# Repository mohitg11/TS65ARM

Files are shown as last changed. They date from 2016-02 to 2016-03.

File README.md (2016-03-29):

# TS65 - ARM Based
The Split 65% Keyboard - ARM Based

This is a custom 65% style keyboard that is split in the middle to provide a more ergonomic option whilest not being drastically different from the standard stagger used on keyboards

#Features
- Open Source Design
- Fully Programmable Keys
- Split design for better ergonomics, while maintaining the currently "standard" keyboard layout
- PCBs and case designed so that the two sides can be connected into standard 65% without split
- Infinite layers
- Alps & Cherry (PCB and Plate) switches supported
- PCB mount stabs supported
- All keys individually lit. LED on top to maintain compatibility with the few backlit keysets out there
- 18 RGB SMD LEDs on the bottom of the PCB for under/side glow
- 3 indicator LEDs
- Individual resistors for the LEDs not required as it uses a dedicated LED driver
- Either side (Left or right) can be connected to the PC
- USB 3.0 Type A and USB Type C are used.
- Using larger (0805) capacitors and resistors so it is easy to hand-solder
- SMD (SOD-123) diodes only

#Layout options
- Split backspace
- Split left shift
- ISO support
- Off-center capslock
- 2.75 and 1.75 right shift
- Lots of options for bottom row

In the below image you can see the different options available, the top four rows represent the four rows of th keyboard and the options for the final keyboard row is represented by the remaining rows in the image.
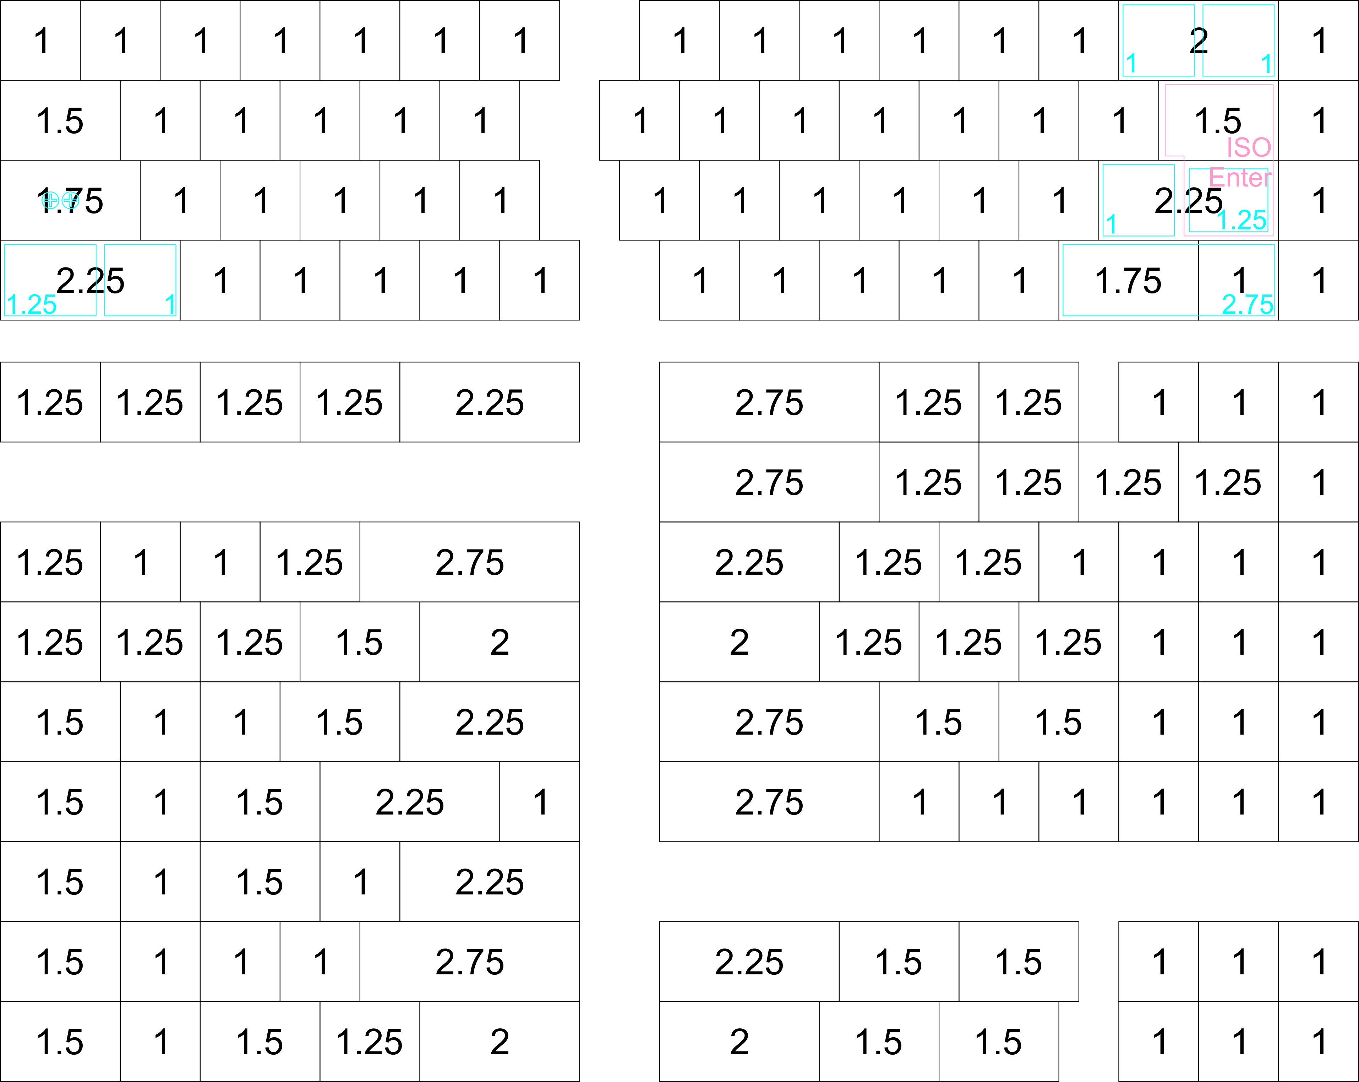
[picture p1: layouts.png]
Layout Options


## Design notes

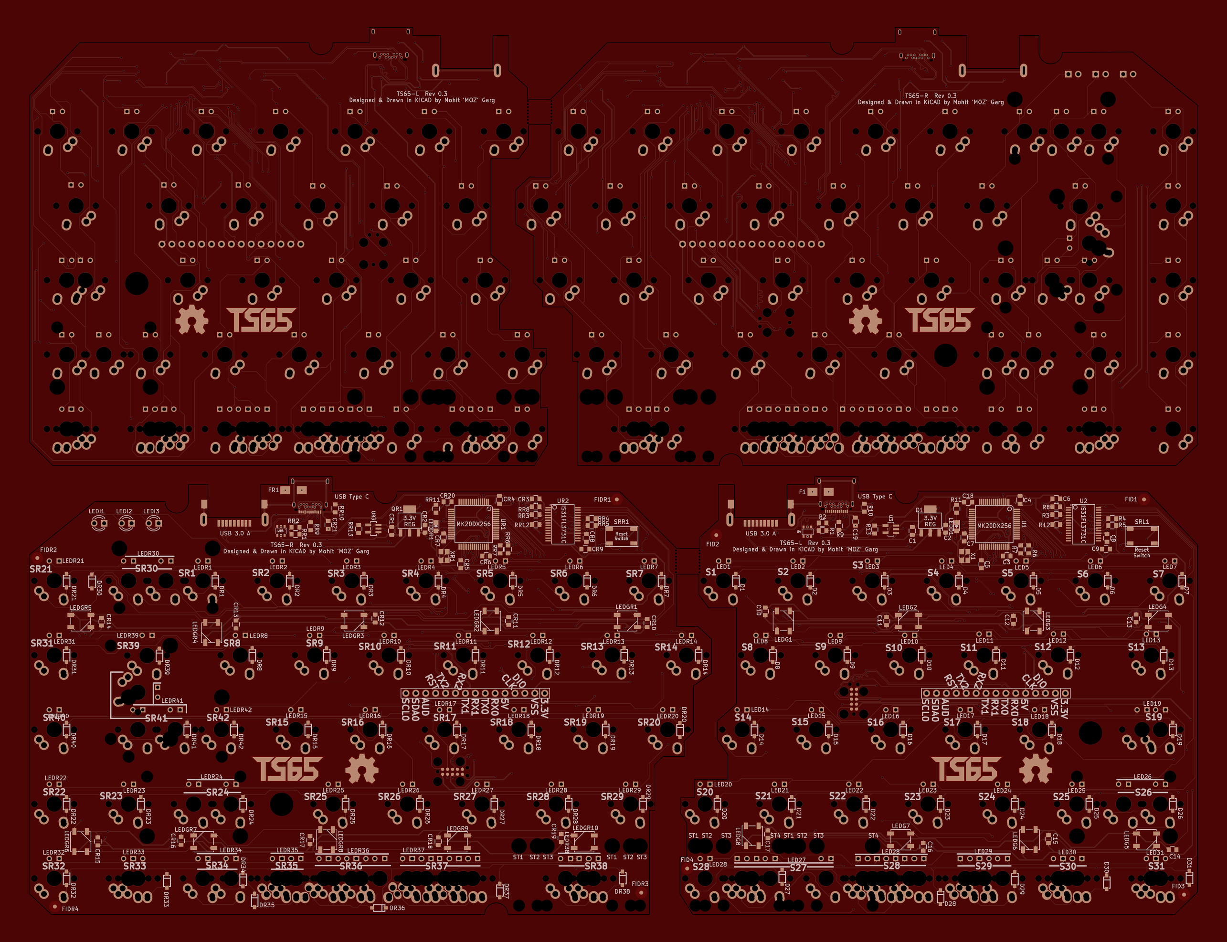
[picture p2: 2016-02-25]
PCBOutput.png

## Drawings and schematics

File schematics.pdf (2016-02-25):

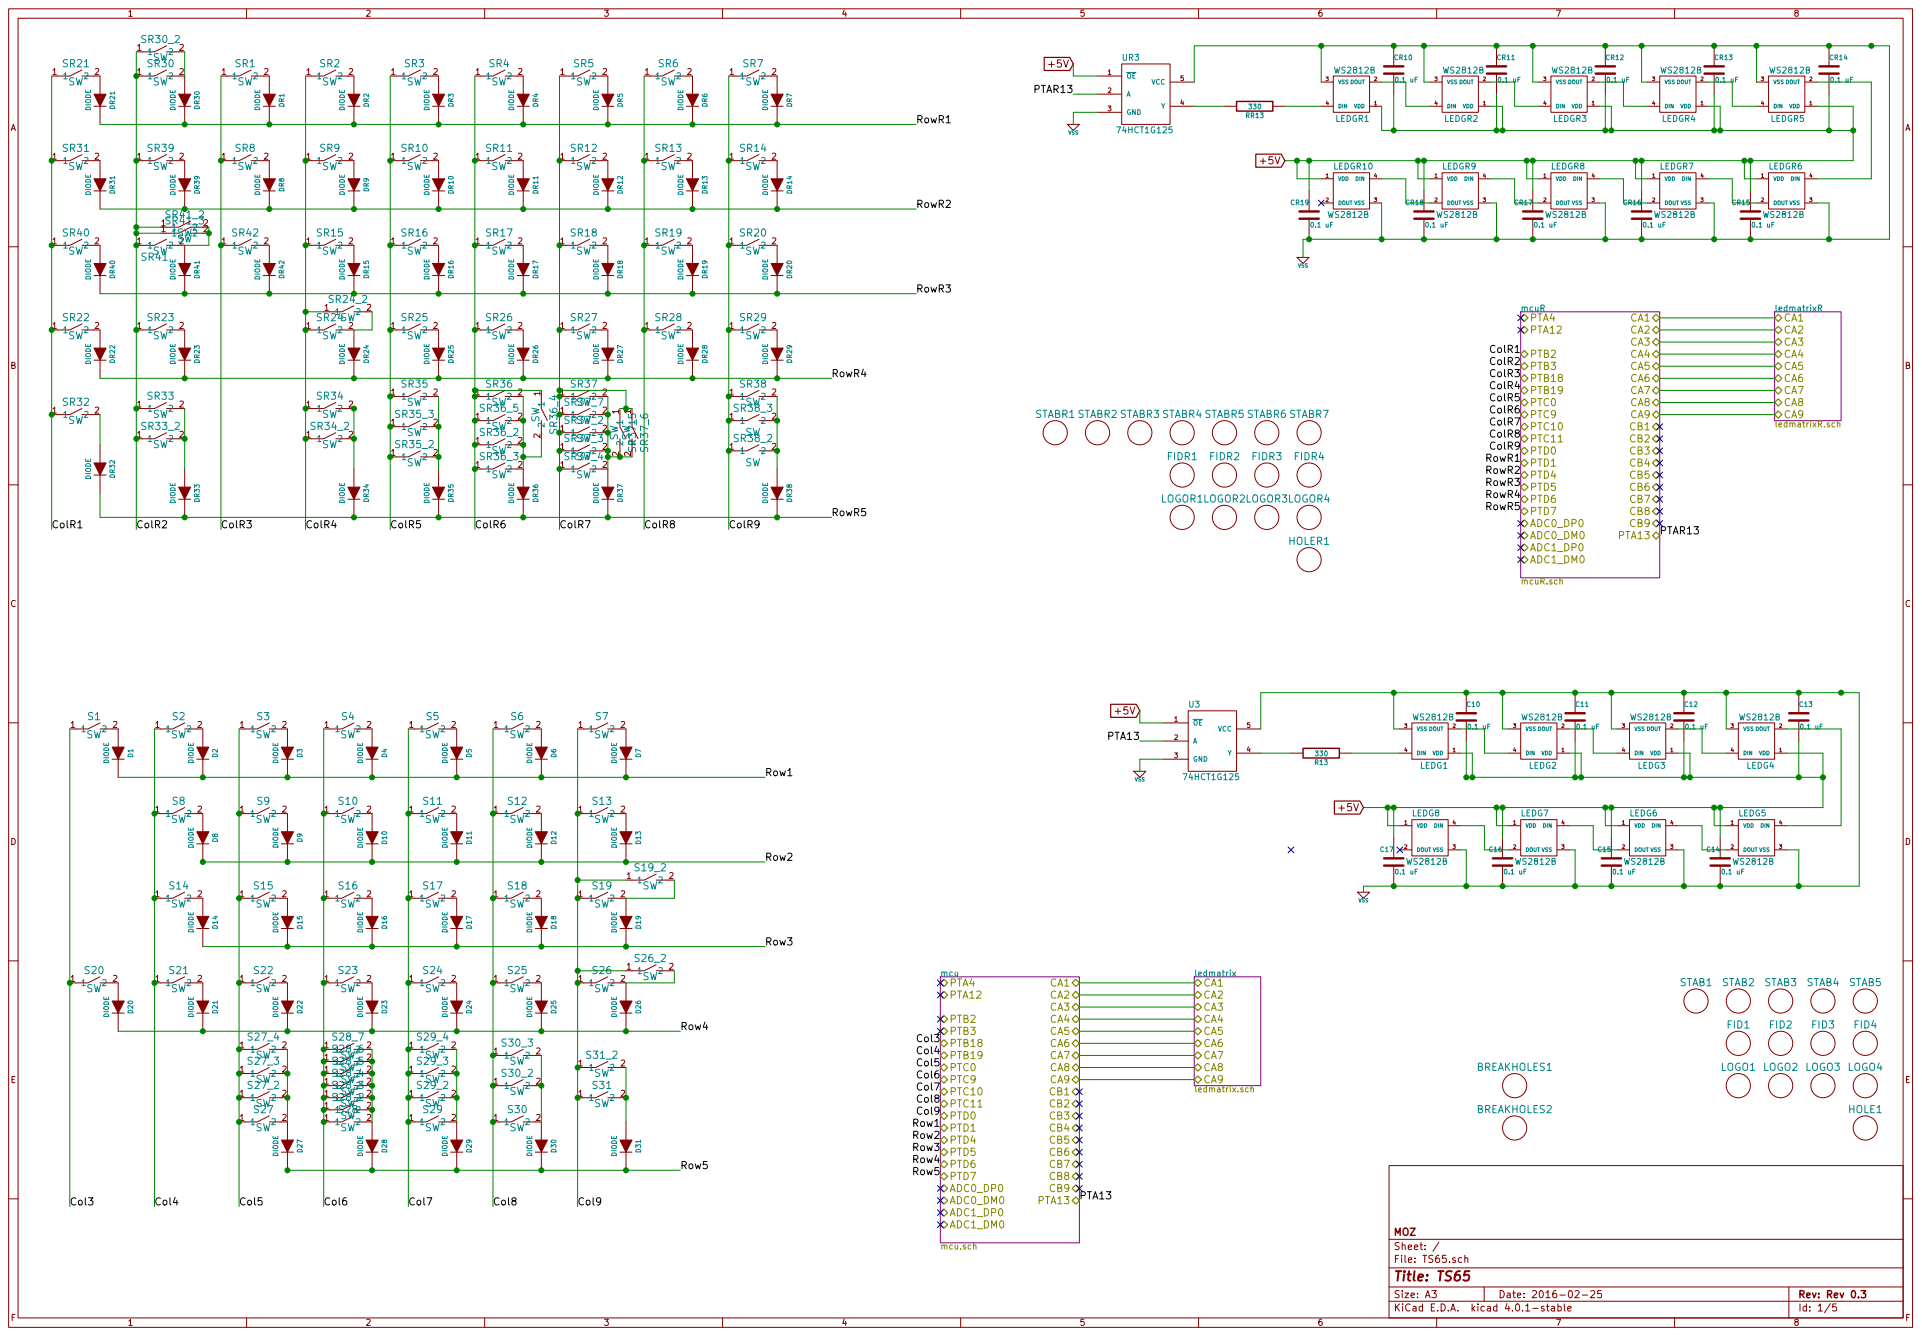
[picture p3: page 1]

File: TS65.sch Sheet: / MOZ

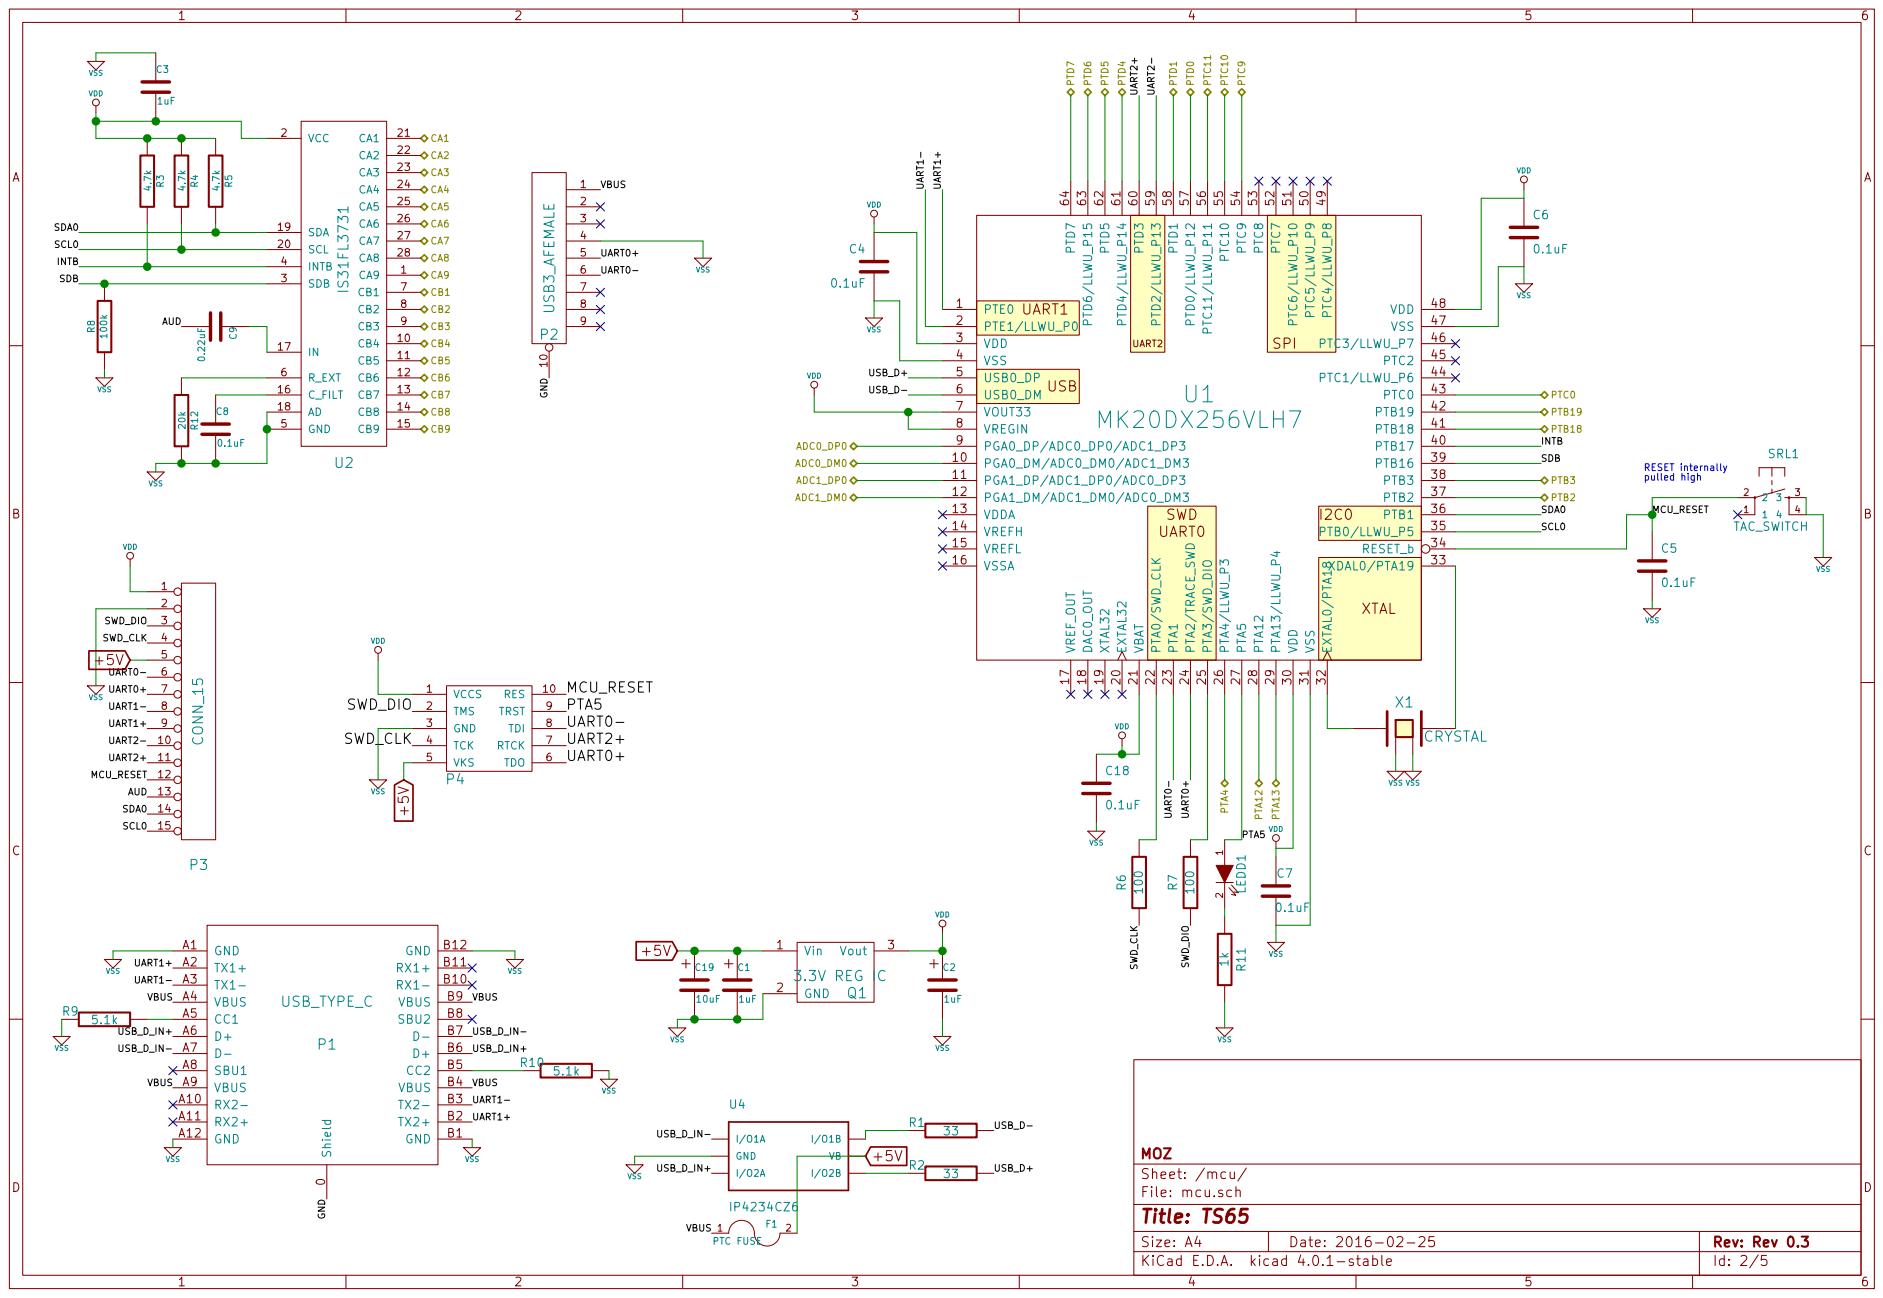
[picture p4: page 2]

0 GND A1 GND B1 TX1+ A2 TX2+ B2 TX1- A3 TX2- B3 VBUS A4 VBUS B4 CC1 A5 CC2 B5 D+ A6 D+ B6 D- A7 D- B7 SBU1 A8 SBU2 B8 VBUS A9 VBUS B9 RX2- A10 RX1- B10 RX2+ A11 RX1+ B11 GND A12 GND B12 P1 USB_TYPE_C

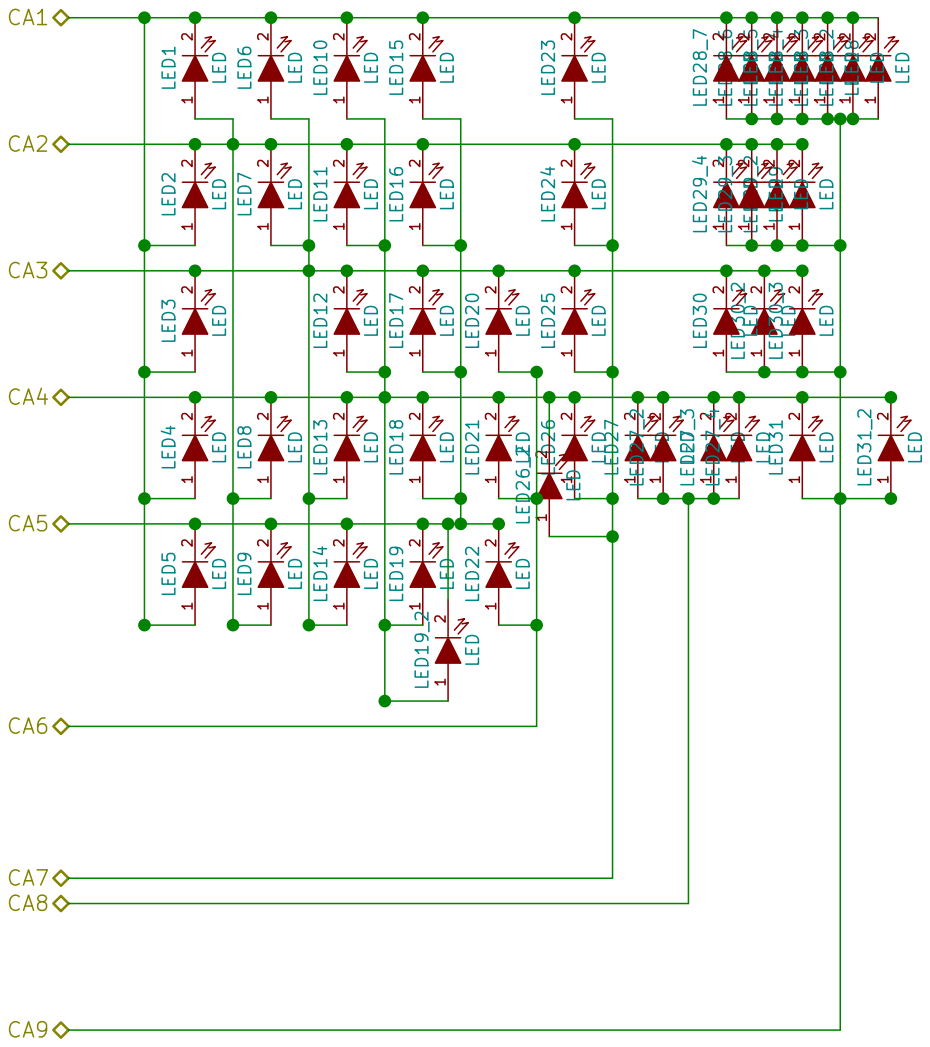
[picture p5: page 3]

File: ledmatrix.sch Sheet: /ledmatrix/ MOZ

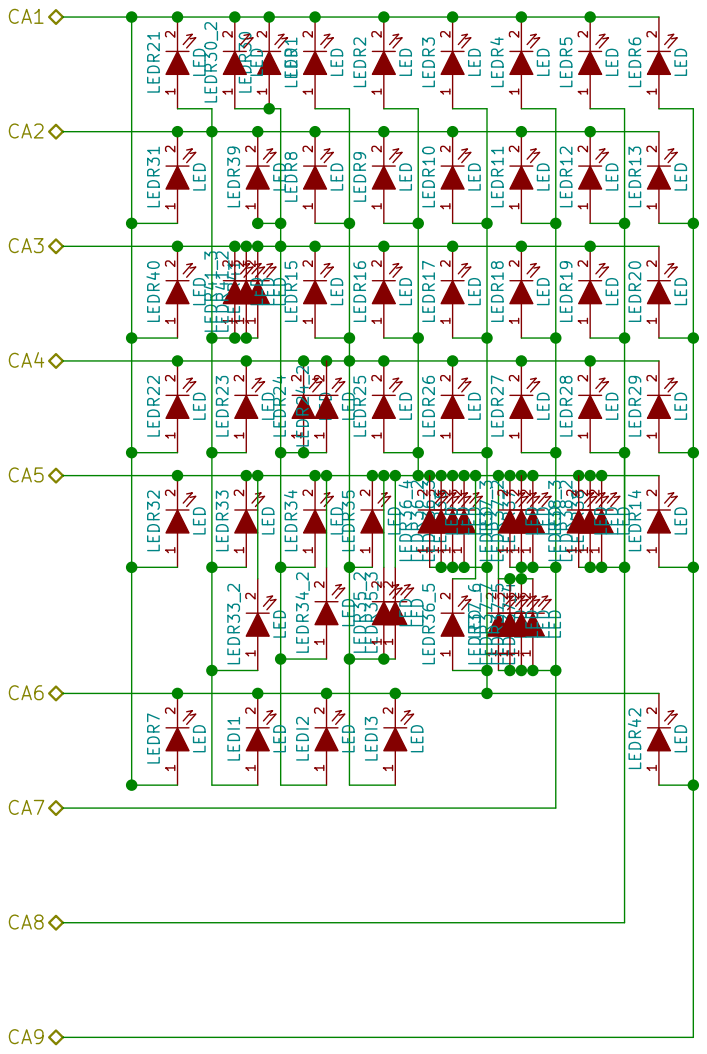
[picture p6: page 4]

File: ledmatrixR.sch Sheet: /ledmatrixR/ MOZ

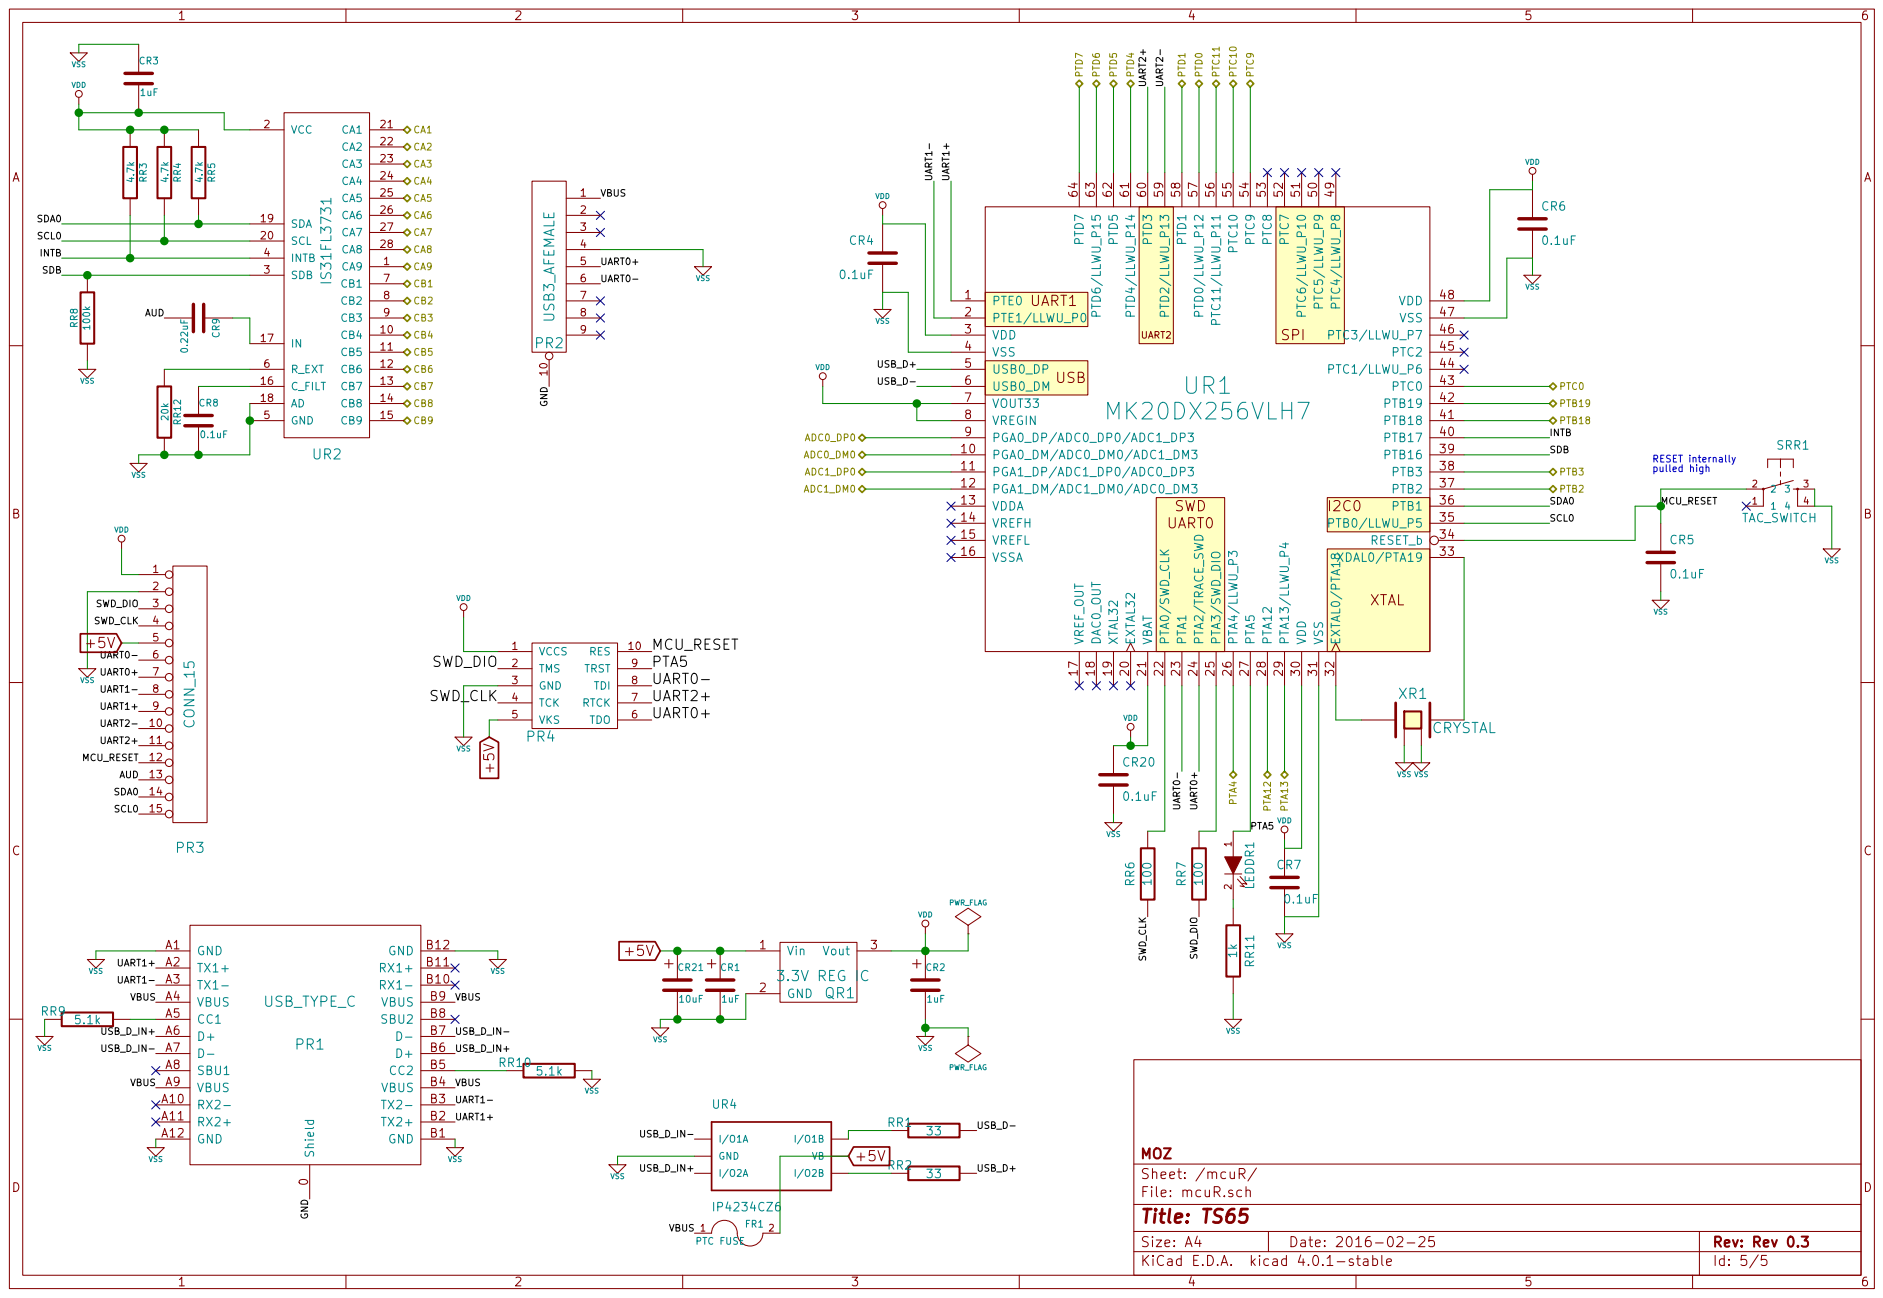
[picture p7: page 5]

0 GND A1 GND B1 TX1+ A2 TX2+ B2 TX1- A3 TX2- B3 VBUS A4 VBUS B4 CC1 A5 CC2 B5 D+ A6 D+ B6 D- A7 D- B7 SBU1 A8 SBU2 B8 VBUS A9 VBUS B9 RX2- A10 RX1- B10 RX2+ A11 RX1+ B11 GND A12 GND B12 PR1 USB_TYPE_C

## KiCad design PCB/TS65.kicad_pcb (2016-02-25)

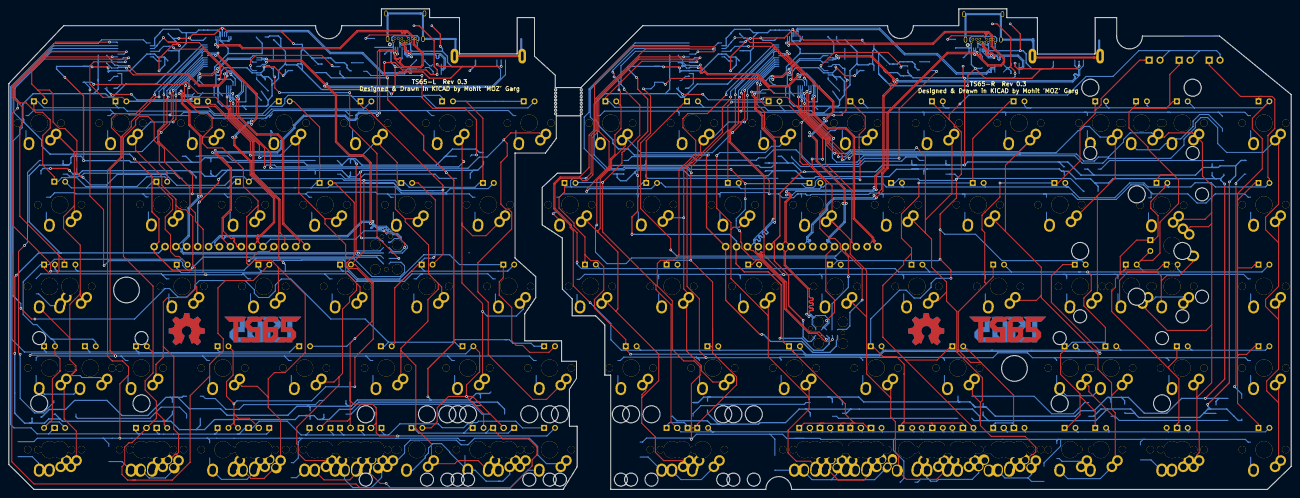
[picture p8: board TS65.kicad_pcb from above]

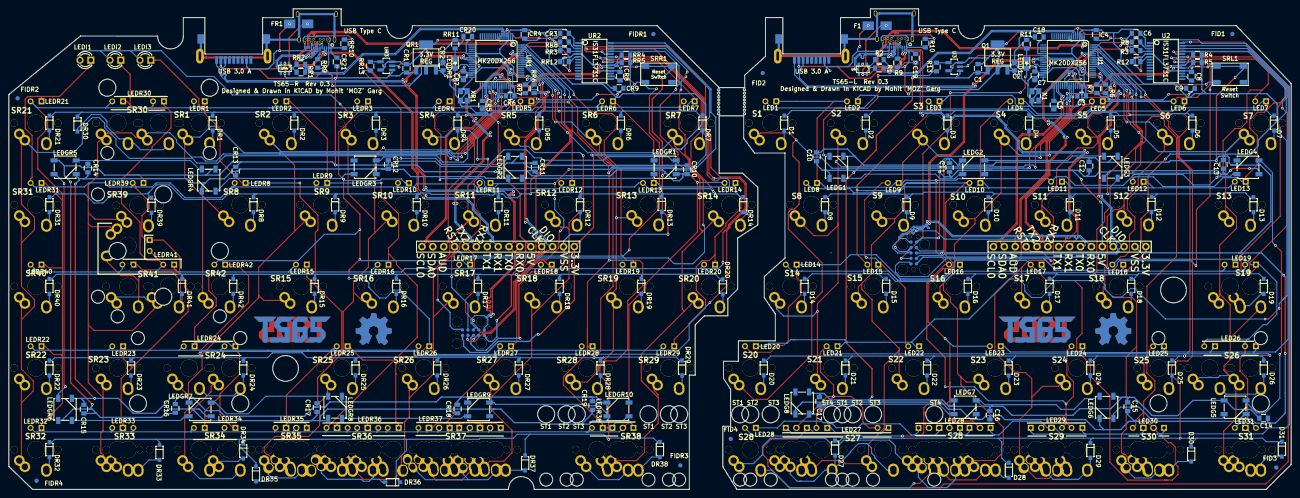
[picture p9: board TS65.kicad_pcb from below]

Board: 2 copper layers, 299.2 x 112.1 mm, 438 parts (198 on the bottom side), 208 nets.

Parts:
BREAKHOLES1, BREAKHOLES2: MISC; BreakHoles
C1, C2, C3: 1uF; SMD_0805
C4, C5, C6, C7, C8, C18: 0.1uF; SMD_0805
C9: 0.22uF; SMD_0805
C10, C11, C12, C13, C14, C15, C16, C17: 0.1 uF; SMD_0805
C19: 10uF; SMD_0805
CR1, CR2, CR3: 1uF; SMD_0805
CR4, CR5, CR6, CR7, CR8, CR20: 0.1uF; SMD_0805
CR9: 0.22uF; SMD_0805
CR10, CR11, CR12, CR13, CR14, CR15, CR16, CR17, CR18, CR19: 0.1 uF; SMD_0805
CR21: 10uF; SMD_0805
D1, D2, D3, D4, D5, D6, D7, D8, D9, D10, D11, D12, D13, D14, D15, D16, D17, D18, D19, D20, D21, D22, D23, D24, D25, D26, D27, D28, D29, D30, D31: DIODE; SOD123-DIODE
DR1, DR2, DR3, DR4, DR5, DR6, DR7, DR8, DR9, DR10, DR11, DR12, DR13, DR14, DR15, DR16, DR17, DR18, DR19, DR20, DR21, DR22, DR23, DR24, DR25, DR26, DR27, DR28, DR29, DR30, DR31, DR32, DR33, DR34, DR35, DR36, DR37, DR38, DR39, DR40, DR41, DR42: DIODE; SOD123-DIODE
F1: PTC FUSE; Fuse_SMD1206_HandSoldering
FID1, FID2, FID3, FID4: MISC; FID
FIDR1, FIDR2, FIDR3, FIDR4: MISC; FID
FR1: PTC FUSE; Fuse_SMD1206_HandSoldering
HOLE1: MISC; FID
HOLER1: MISC; FID
LED1, LED2, LED3, LED4, LED5, LED6, LED7, LED8, LED9, LED10, LED11, LED12, LED13, LED14, LED15, LED16, LED17, LED18, LED19, LED19_2, LED20, LED21, LED22, LED23, LED24, LED25, LED26, LED26_2, LED27, LED27_2, LED27_3, LED27_4, LED28, LED28_2, LED28_3, LED28_4, LED28_5, LED28_6, LED28_7, LED29, LED29_2, LED29_3, LED29_4, LED30, LED30_2, LED30_3, LED31, LED31_2: LED; INSW_LEDS_REG
LEDD1: LED; LED_0805
LEDDR1: LED; LED_0805
LEDG1, LEDG2, LEDG3, LEDG4, LEDG5, LEDG6, LEDG7, LEDG8: WS2812B
LEDGR1, LEDGR2, LEDGR3, LEDGR4, LEDGR5, LEDGR6, LEDGR7, LEDGR8, LEDGR9, LEDGR10: WS2812B
LEDI1, LEDI2, LEDI3: LED; LED-3MM
LEDR1, LEDR2, LEDR3, LEDR4, LEDR5, LEDR6, LEDR7, LEDR8, LEDR9, LEDR10, LEDR11, LEDR12, LEDR13, LEDR14, LEDR15, LEDR16, LEDR17, LEDR18, LEDR19, LEDR20, LEDR21, LEDR22, LEDR23, LEDR24, LEDR24_2, LEDR25, LEDR26, LEDR27, LEDR28, LEDR29, LEDR30, LEDR30_2, LEDR31, LEDR32, LEDR33, LEDR33_2, LEDR34, LEDR34_2, LEDR35, LEDR35_2, LEDR35_3, LEDR36, LEDR36_2, LEDR36_3, LEDR36_4, LEDR36_5, LEDR37, LEDR37_2, LEDR37_3, LEDR37_4, LEDR37_5, LEDR37_6, LEDR37_7, LEDR38, LEDR38_2, LEDR38_3, LEDR39, LEDR40, LEDR41, LEDR41_2, LEDR41_3, LEDR42: LED; INSW_LEDS_REG
LOGO1, LOGO2: MISC; TS65-LOGO
LOGO3, LOGO4: MISC; OSHW
LOGOR1, LOGOR2: MISC; TS65-LOGO
LOGOR3, LOGOR4: MISC; OSHW
P1: USB_TYPE_C; USB_TYPE_C_HYBRID
P2: USB3_AFEMALE; USB3_AFEMALE_MOD
P3: CONN_15; HEADER_1x15
P4: FLASH_HDR; JLINK_NEEDLE
PR1: USB_TYPE_C; USB_TYPE_C_HYBRID
PR2: USB3_AFEMALE; USB3_AFEMALE_MOD
PR3: CONN_15; HEADER_1x15
PR4: FLASH_HDR; JLINK_NEEDLE
Q1: 3.3V REG IC; SOT-223
QR1: 3.3V REG IC; SOT-223
R1, R2: 33; SMD_0805
R3, R4, R5: 4.7k; SMD_0805
R6, R7: 100; SMD_0805
R8: 100k; SMD_0805
R9, R10: 5.1k; SMD_0805
R11: 1k; SMD_0805
R12: 20k; SMD_0805
R13: 330; SMD_0805
RR1, RR2: 33; SMD_0805
RR3, RR4, RR5: 4.7k; SMD_0805
RR6, RR7: 100; SMD_0805
RR8: 100k; SMD_0805
RR9, RR10: 5.1k; SMD_0805
RR11: 1k; SMD_0805
RR12: 20k; SMD_0805
RR13: 330; SMD_0805
S1, S2, S3, S4, S5, S6, S7, S8, S9, S10, S11, S12, S13, S14, S15, S16, S17, S18, S19, S19_2, S20, S21, S22, S23, S24, S25, S26, S26_2, S27, S27_2, S27_3, S27_4, S28, S28_2, S28_3, S28_4, S28_5, S28_6, S28_7, S29, S29_2, S29_3, S29_4, S30, S30_2, S30_3, S31, S31_2: SW; MXALPS2
SR1, SR2, SR3, SR4, SR5, SR6, SR7, SR8, SR9, SR10, SR11, SR12, SR13, SR14, SR15, SR16, SR17, SR18, SR19, SR20, SR21, SR22, SR23, SR24, SR24_2, SR25, SR26, SR27, SR28, SR29, SR30, SR30_2, SR31, SR32, SR33, SR33_2, SR34, SR34_2, SR35, SR35_2, SR35_3, SR36, SR36_2, SR36_3, SR36_4, SR36_5, SR37, SR37_2, SR37_3, SR37_4, SR37_5, SR37_6, SR37_7, SR38, SR38_2, SR38_3, SR39, SR40, SR41, SR41_2, SR41_3, SR42: SW; MXALPS2
SRL1: TAC_SWITCH; TACT_5.2x5.2
SRR1: TAC_SWITCH; TACT_5.2x5.2
STAB1, STAB2, STAB3, STAB4, STAB5: MISC; MX_200
STABR1, STABR2, STABR3, STABR4, STABR5, STABR6, STABR7: MISC; MX_200
U1: MK20DX256VLH7; LQFP64
U2: IS31FL3731; SSOP-28
U3: 74HCT1G125; SOT-753
U4: IP4234CZ6; SOT457
UR1: MK20DX256VLH7; LQFP64
UR2: IS31FL3731; SSOP-28
UR3: 74HCT1G125; SOT-753
UR4: IP4234CZ6; SOT457
X1: CRYSTAL; NX3225SA
XR1: CRYSTAL; NX3225SA

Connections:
+5V: C1.1, C10.2, C11.2, C12.2, C13.2, C14.1, C15.1, C16.1, C17.1, C19.1, CR1.1, CR10.2, CR11.2, CR12.2, CR13.2, CR14.2, CR15.1, CR16.1, CR17.1, CR18.1, CR19.1, CR21.1, F1.2, FR1.2, LEDG1.1, LEDG2.1, LEDG3.1, LEDG4.1, LEDG5.1, LEDG6.1, LEDG7.1, LEDG8.1, LEDGR1.1, LEDGR2.1, LEDGR3.1, LEDGR4.1, LEDGR5.1, LEDGR6.1, LEDGR7.1, LEDGR8.1, LEDGR9.1, LEDGR10.1, P3.5, P4.5, PR3.5, PR4.5, Q1.1, QR1.1, U3.1, U4.5, UR3.1, UR4.5
/ledmatrix/CA1: LED1.2, LED2.1, LED3.1, LED4.1, LED5.1, LED6.2, LED10.2, LED15.2, LED23.2, LED28.2, LED28_2.2, LED28_3.2, LED28_4.2, LED28_5.2, LED28_6.2, LED28_7.2, U2.21
/ledmatrix/CA2: LED1.1, LED2.2, LED7.2, LED8.1, LED9.1, LED11.2, LED16.2, LED24.2, LED29.2, LED29_2.2, LED29_3.2, LED29_4.2, U2.22
/ledmatrix/CA3: LED3.2, LED6.1, LED7.1, LED12.2, LED13.1, LED14.1, LED17.2, LED20.2, LED25.2, LED30.2, LED30_2.2, LED30_3.2, U2.23
/ledmatrix/CA4: LED4.2, LED8.2, LED10.1, LED11.1, LED12.1, LED13.2, LED18.2, LED19.1, LED19_2.1, LED21.2, LED26.2, LED26_2.2, LED27.2, LED27_2.2, LED27_3.2, LED27_4.2, LED31.2, LED31_2.2, U2.24
/ledmatrix/CA5: LED5.2, LED9.2, LED14.2, LED15.1, LED16.1, LED17.1, LED18.1, LED19.2, LED19_2.2, LED22.2, U2.25
/ledmatrix/CA6: LED20.1, LED21.1, LED22.1, U2.26
/ledmatrix/CA7: LED23.1, LED24.1, LED25.1, LED26.1, LED26_2.1, U2.27
/ledmatrix/CA8: LED27.1, LED27_2.1, LED27_3.1, LED27_4.1, U2.28
/ledmatrix/CA9: LED28.1, LED28_2.1, LED28_3.1, LED28_4.1, LED28_5.1, LED28_6.1, LED28_7.1, LED29.1, LED29_2.1, LED29_3.1, LED29_4.1, LED30.1, LED30_2.1, LED30_3.1, LED31.1, LED31_2.1, U2.1
/ledmatrixR/CA1: LEDR1.2, LEDR2.2, LEDR3.2, LEDR4.2, LEDR5.2, LEDR6.2, LEDR7.1, LEDR21.2, LEDR22.1, LEDR30.2, LEDR30_2.2, LEDR31.1, LEDR32.1, LEDR40.1, UR2.21
/ledmatrixR/CA2: LEDI1.1, LEDR8.2, LEDR9.2, LEDR10.2, LEDR11.2, LEDR12.2, LEDR13.2, LEDR21.1, LEDR23.1, LEDR31.2, LEDR33.1, LEDR33_2.1, LEDR39.2, LEDR41.1, LEDR41_2.1, LEDR41_3.1, UR2.22
/ledmatrixR/CA3: LEDI2.1, LEDR15.2, LEDR16.2, LEDR17.2, LEDR18.2, LEDR19.2, LEDR20.2, LEDR24.1, LEDR24_2.1, LEDR30.1, LEDR30_2.1, LEDR34.1, LEDR34_2.1, LEDR39.1, LEDR40.2, LEDR41.2, LEDR41_2.2, LEDR41_3.2, UR2.23
/ledmatrixR/CA4: LEDI3.1, LEDR1.1, LEDR8.1, LEDR15.1, LEDR22.2, LEDR23.2, LEDR24.2, LEDR24_2.2, LEDR25.2, LEDR26.2, LEDR27.2, LEDR28.2, LEDR29.2, LEDR35.1, LEDR35_2.1, LEDR35_3.1, UR2.24
/ledmatrixR/CA5: LEDR2.1, LEDR9.1, LEDR14.2, LEDR16.1, LEDR25.1, LEDR32.2, LEDR33.2, LEDR33_2.2, LEDR34.2, LEDR34_2.2, LEDR35.2, LEDR35_2.2, LEDR35_3.2, LEDR36.2, LEDR36_2.2, LEDR36_3.2, LEDR36_4.2, LEDR36_5.2, LEDR37.2, LEDR37_2.2, LEDR37_3.2, LEDR37_4.2, LEDR37_5.2, LEDR37_6.2, LEDR37_7.2, LEDR38.2, LEDR38_2.2, LEDR38_3.2, UR2.25
/ledmatrixR/CA6: LEDI1.2, LEDI2.2, LEDI3.2, LEDR3.1, LEDR7.2, LEDR10.1, LEDR17.1, LEDR26.1, LEDR36.1, LEDR36_2.1, LEDR36_3.1, LEDR36_4.1, LEDR36_5.1, LEDR42.2, UR2.26
/ledmatrixR/CA7: LEDR4.1, LEDR11.1, LEDR18.1, LEDR27.1, LEDR37.1, LEDR37_2.1, LEDR37_3.1, LEDR37_4.1, LEDR37_5.1, LEDR37_6.1, LEDR37_7.1, UR2.27
/ledmatrixR/CA8: LEDR5.1, LEDR12.1, LEDR19.1, LEDR28.1, LEDR38.1, LEDR38_2.1, LEDR38_3.1, UR2.28
/ledmatrixR/CA9: LEDR6.1, LEDR13.1, LEDR14.1, LEDR20.1, LEDR29.1, LEDR42.1, UR2.1
/mcu/AUD: C9.2, P3.13
/mcu/GND: P1.0, P2.10
/mcu/INTB: R3.2, U1.40, U2.4
/mcu/MCU_RESET: C5.1, P3.12, P4.10, SRL1.2, U1.34
/mcu/PTA5: LEDD1.1, P4.9, U1.27
/mcu/PTA13: U1.29, U3.2
/mcu/PTB18: S1.1, S20.1, U1.41
/mcu/PTB19: S2.1, S8.1, S14.1, S21.1, U1.42
/mcu/PTC0: S3.1, S9.1, S15.1, S22.1, S27.1, S27_2.1, S27_3.1, S27_4.1, U1.43
/mcu/PTC9: S4.1, S10.1, S16.1, S23.1, S28.1, S28_2.1, S28_3.1, S28_4.1, S28_5.1, S28_6.1, S28_7.1, U1.54
/mcu/PTC10: S5.1, S11.1, S17.1, S24.1, S29.1, S29_2.1, S29_3.1, S29_4.1, U1.55
/mcu/PTC11: S6.1, S12.1, S18.1, S25.1, S30.1, S30_2.1, S30_3.1, U1.56
/mcu/PTD0: S7.1, S13.1, S19.1, S19_2.1, S26.1, S26_2.1, S31.1, S31_2.1, U1.57
/mcu/PTD1: D1.2, D2.2, D3.2, D4.2, D5.2, D6.2, D7.2, U1.58
/mcu/PTD4: D8.2, D9.2, D10.2, D11.2, D12.2, D13.2, U1.61
/mcu/PTD5: D14.2, D15.2, D16.2, D17.2, D18.2, D19.2, U1.62
/mcu/PTD6: D20.2, D21.2, D22.2, D23.2, D24.2, D25.2, D26.2, U1.63
/mcu/PTD7: D27.2, D28.2, D29.2, D30.2, D31.2, U1.64
/mcu/SCL0: P3.15, R4.2, U1.35, U2.20
/mcu/SDA0: P3.14, R5.2, U1.36, U2.19
/mcu/SDB: R8.2, U1.39, U2.3
/mcu/SWD_CLK: P3.4, P4.4, R6.2
/mcu/SWD_DIO: P3.3, P4.2, R7.2
/mcu/UART0+: P2.5, P3.7, P4.6, U1.24
/mcu/UART0-: P2.6, P3.6, P4.8, U1.23
/mcu/UART1+: P1.A2, P1.B2, P3.9, U1.1
/mcu/UART1-: P1.A3, P1.B3, P3.8, U1.2
/mcu/UART2+: P3.11, P4.7, U1.60
/mcu/UART2-: P3.10, U1.59
/mcu/USB_D+: R2.2, U1.5
/mcu/USB_D-: R1.2, U1.6
/mcu/USB_D_IN+: P1.A6, P1.B6, U4.3
/mcu/USB_D_IN-: P1.A7, P1.B7, U4.4
/mcu/VBUS: F1.1, P1.A4, P1.A9, P1.B4, P1.B9, P2.1
/mcuR/AUD: CR9.2, PR3.13
/mcuR/GND: PR1.0, PR2.10
/mcuR/INTB: RR3.2, UR1.40, UR2.4
/mcuR/MCU_RESET: CR5.1, PR3.12, PR4.10, SRR1.2, UR1.34
/mcuR/PTA5: LEDDR1.1, PR4.9, UR1.27
/mcuR/PTA13: UR1.29, UR3.2
/mcuR/PTB2: SR21.1, SR22.1, SR31.1, SR32.1, SR40.1, UR1.37
/mcuR/PTB3: SR23.1, SR30.1, SR30_2.1, SR33.1, SR33_2.1, SR39.1, SR41.1, SR41_2.1, SR41_3.1, UR1.38
/mcuR/PTB18: SR1.1, SR8.1, SR42.1, UR1.41
/mcuR/PTB19: SR2.1, SR9.1, SR15.1, SR24.1, SR24_2.1, SR34.1, SR34_2.1, UR1.42
/mcuR/PTC0: SR3.1, SR10.1, SR16.1, SR25.1, SR35.1, SR35_2.1, SR35_3.1, UR1.43
/mcuR/PTC9: SR4.1, SR11.1, SR17.1, SR26.1, SR36.1, SR36_2.1, SR36_3.1, SR36_4.1, SR36_5.1, UR1.54
/mcuR/PTC10: SR5.1, SR12.1, SR18.1, SR27.1, SR37.1, SR37_2.1, SR37_3.1, SR37_4.1, SR37_5.1, SR37_6.1, SR37_7.1, UR1.55
/mcuR/PTC11: SR6.1, SR13.1, SR19.1, SR28.1, UR1.56
/mcuR/PTD0: SR7.1, SR14.1, SR20.1, SR29.1, SR38.1, SR38_2.1, SR38_3.1, UR1.57
/mcuR/PTD1: DR1.2, DR2.2, DR3.2, DR4.2, DR5.2, DR6.2, DR7.2, DR21.2, DR30.2, UR1.58
/mcuR/PTD4: DR8.2, DR9.2, DR10.2, DR11.2, DR12.2, DR13.2, DR14.2, DR31.2, DR39.2, UR1.61
/mcuR/PTD5: DR15.2, DR16.2, DR17.2, DR18.2, DR19.2, DR20.2, DR40.2, DR41.2, DR42.2, UR1.62
/mcuR/PTD6: DR22.2, DR23.2, DR24.2, DR25.2, DR26.2, DR27.2, DR28.2, DR29.2, UR1.63
/mcuR/PTD7: DR32.2, DR33.2, DR34.2, DR35.2, DR36.2, DR37.2, DR38.2, UR1.64
/mcuR/SCL0: PR3.15, RR4.2, UR1.35, UR2.20
/mcuR/SDA0: PR3.14, RR5.2, UR1.36, UR2.19
/mcuR/SDB: RR8.2, UR1.39, UR2.3
/mcuR/SWD_CLK: PR3.4, PR4.4, RR6.2
/mcuR/SWD_DIO: PR3.3, PR4.2, RR7.2
/mcuR/UART0+: PR2.5, PR3.7, PR4.6, UR1.24
/mcuR/UART0-: PR2.6, PR3.6, PR4.8, UR1.23
/mcuR/UART1+: PR1.A2, PR1.B2, PR3.9, UR1.1
/mcuR/UART1-: PR1.A3, PR1.B3, PR3.8, UR1.2
/mcuR/UART2+: PR3.11, PR4.7, UR1.60
/mcuR/UART2-: PR3.10, UR1.59
/mcuR/USB_D+: RR2.2, UR1.5
/mcuR/USB_D-: RR1.2, UR1.6
/mcuR/USB_D_IN+: PR1.A6, PR1.B6, UR4.3
/mcuR/USB_D_IN-: PR1.A7, PR1.B7, UR4.4
/mcuR/VBUS: FR1.1, PR1.A4, PR1.A9, PR1.B4, PR1.B9, PR2.1
unnamed: C8.1, U2.16
unnamed: C9.1, U2.17
unnamed: CR8.1, UR2.16
unnamed: CR9.1, UR2.17
unnamed: D1.1, S1.2
unnamed: D2.1, S2.2
unnamed: D3.1, S3.2
unnamed: D4.1, S4.2
unnamed: D5.1, S5.2
unnamed: D6.1, S6.2
unnamed: D7.1, S7.2
unnamed: D8.1, S8.2
unnamed: D9.1, S9.2
unnamed: D10.1, S10.2
unnamed: D11.1, S11.2
unnamed: D12.1, S12.2
unnamed: D13.1, S13.2
unnamed: D14.1, S14.2
unnamed: D15.1, S15.2
unnamed: D16.1, S16.2
unnamed: D17.1, S17.2
unnamed: D18.1, S18.2
unnamed: D19.1, S19.2, S19_2.2
unnamed: D20.1, S20.2
unnamed: D21.1, S21.2
unnamed: D22.1, S22.2
unnamed: D23.1, S23.2
unnamed: D24.1, S24.2
unnamed: D25.1, S25.2
unnamed: D26.1, S26.2, S26_2.2
unnamed: D27.1, S27.2, S27_2.2, S27_3.2, S27_4.2
unnamed: D28.1, S28.2, S28_2.2, S28_3.2, S28_4.2, S28_5.2, S28_6.2, S28_7.2
unnamed: D29.1, S29.2, S29_2.2, S29_3.2, S29_4.2
unnamed: D30.1, S30.2, S30_2.2, S30_3.2
unnamed: D31.1, S31.2, S31_2.2
unnamed: DR1.1, SR1.2
unnamed: DR2.1, SR2.2
unnamed: DR3.1, SR3.2
unnamed: DR4.1, SR4.2
unnamed: DR5.1, SR5.2
unnamed: DR6.1, SR6.2
unnamed: DR7.1, SR7.2
unnamed: DR8.1, SR8.2
unnamed: DR9.1, SR9.2
unnamed: DR10.1, SR10.2
unnamed: DR11.1, SR11.2
unnamed: DR12.1, SR12.2
unnamed: DR13.1, SR13.2
unnamed: DR14.1, SR14.2
unnamed: DR15.1, SR15.2
unnamed: DR16.1, SR16.2
unnamed: DR17.1, SR17.2
unnamed: DR18.1, SR18.2
unnamed: DR19.1, SR19.2
unnamed: DR20.1, SR20.2
unnamed: DR21.1, SR21.2
unnamed: DR22.1, SR22.2
unnamed: DR23.1, SR23.2
unnamed: DR24.1, SR24.2, SR24_2.2
unnamed: DR25.1, SR25.2
unnamed: DR26.1, SR26.2
unnamed: DR27.1, SR27.2
unnamed: DR28.1, SR28.2
unnamed: DR29.1, SR29.2
unnamed: DR30.1, SR30.2, SR30_2.2
unnamed: DR31.1, SR31.2
unnamed: DR32.1, SR32.2
unnamed: DR33.1, SR33.2, SR33_2.2
unnamed: DR34.1, SR34.2, SR34_2.2
unnamed: DR35.1, SR35.2, SR35_2.2, SR35_3.2
unnamed: DR36.1, SR36.2, SR36_2.2, SR36_3.2, SR36_4.2, SR36_5.2
unnamed: DR37.1, SR37.2, SR37_2.2, SR37_3.2, SR37_4.2, SR37_5.2, SR37_6.2, SR37_7.2
unnamed: DR38.1, SR38.2, SR38_2.2, SR38_3.2
unnamed: DR39.1, SR39.2
unnamed: DR40.1, SR40.2
unnamed: DR41.1, SR41.2, SR41_2.2, SR41_3.2
unnamed: DR42.1, SR42.2
unnamed: LEDD1.2, R11.1
unnamed: LEDDR1.2, RR11.1
unnamed: LEDG1.2, LEDG2.4
unnamed: LEDG1.4, R13.1
unnamed: LEDG2.2, LEDG3.4
unnamed: LEDG3.2, LEDG4.4
unnamed: LEDG4.2, LEDG5.4
unnamed: LEDG5.2, LEDG6.4
unnamed: LEDG6.2, LEDG7.4
unnamed: LEDG7.2, LEDG8.4
unnamed: LEDGR1.2, LEDGR2.4
unnamed: LEDGR1.4, RR13.1
unnamed: LEDGR2.2, LEDGR3.4
unnamed: LEDGR3.2, LEDGR4.4
unnamed: LEDGR4.2, LEDGR5.4
unnamed: LEDGR5.2, LEDGR6.4
unnamed: LEDGR6.2, LEDGR7.4
unnamed: LEDGR7.2, LEDGR8.4
unnamed: LEDGR8.2, LEDGR9.4
unnamed: LEDGR9.2, LEDGR10.4
unnamed: P1.A5, R9.2
unnamed: P1.B5, R10.1
unnamed: PR1.A5, RR9.2
unnamed: PR1.B5, RR10.1
unnamed: R1.1, U4.6
unnamed: R2.1, U4.1
unnamed: R6.1, U1.22
unnamed: R7.1, U1.25
unnamed: R12.1, U2.6
unnamed: R13.2, U3.4
unnamed: RR1.1, UR4.6
unnamed: RR2.1, UR4.1
unnamed: RR6.1, UR1.22
unnamed: RR7.1, UR1.25
unnamed: RR12.1, UR2.6
unnamed: RR13.2, UR3.4
unnamed: U1.32, X1.1
unnamed: U1.33, X1.3
unnamed: UR1.32, XR1.1
unnamed: UR1.33, XR1.3
VDD: C2.1, C3.2, C4.1, C6.1, C7.1, C18.1, CR2.1, CR3.2, CR4.1, CR6.1, CR7.1, CR20.1, P3.1, P4.1, PR3.1, PR4.1, Q1.3, QR1.3, R3.1, R4.1, R5.1, RR3.1, RR4.1, RR5.1, U1.3, U1.7, U1.8, U1.21, U1.30, U1.48, U2.2, UR1.3, UR1.7, UR1.8, UR1.21, UR1.30, UR1.48, UR2.2
VSS: C1.2, C2.2, C3.1, C4.2, C5.2, C6.2, C7.2, C8.2, C10.1, C11.1, C12.1, C13.1, C14.2, C15.2, C16.2, C17.2, C18.2, C19.2, CR1.2, CR2.2, CR3.1, CR4.2, CR5.2, CR6.2, CR7.2, CR8.2, CR10.1, CR11.1, CR12.1, CR13.1, CR14.1, CR15.2, CR16.2, CR17.2, CR18.2, CR19.2, CR20.2, CR21.2, LEDG1.3, LEDG2.3, LEDG3.3, LEDG4.3, LEDG5.3, LEDG6.3, LEDG7.3, LEDG8.3, LEDGR1.3, LEDGR2.3, LEDGR3.3, LEDGR4.3, LEDGR5.3, LEDGR6.3, LEDGR7.3, LEDGR8.3, LEDGR9.3, LEDGR10.3, P1.A1, P1.A12, P1.B1, P1.B12, P2.4, P3.2, P4.3, PR1.A1, PR1.A12, PR1.B1, PR1.B12, PR2.4, PR3.2, PR4.3, Q1.2, QR1.2, R8.1, R9.1, R10.2, R11.2, R12.2, RR8.1, RR9.1, RR10.2, RR11.2, RR12.2, SRL1.3, SRL1.4, SRR1.3, SRR1.4, U1.4, U1.31, U1.47, U2.5, U2.18, U3.3, U3.5, U4.2, UR1.4, UR1.31, UR1.47, UR2.5, UR2.18, UR3.3, UR3.5, UR4.2, X1.2, X1.4, XR1.2, XR1.4

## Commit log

2016-02-01 Initial Upload
    [TS65Left-B.Mask.gbr, TS65Left-B.Paste.gbr, TS65Left-B.SilkS.gbr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]
2016-02-07 Case V1
2016-02-08 Rev 0.2 - Combined left and right sides
    [TS65-B.Mask.gbr, TS65-B.Paste.gbr, TS65-B.SilkS.gbr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]
2016-02-10 Case updated to PCB Rev 0.2
    [TS65.kicad_pcb]
2016-02-25 PCB version 0.3
    Case still to be updated to Rev 0.3
    [TS65-B.Mask.gbr, TS65-B.Paste.gbr, TS65-B.SilkS.gbr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]
